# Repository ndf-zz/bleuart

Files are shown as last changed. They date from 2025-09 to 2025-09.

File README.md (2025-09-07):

# bleuart

ESP32 BLE to RS232 bridge

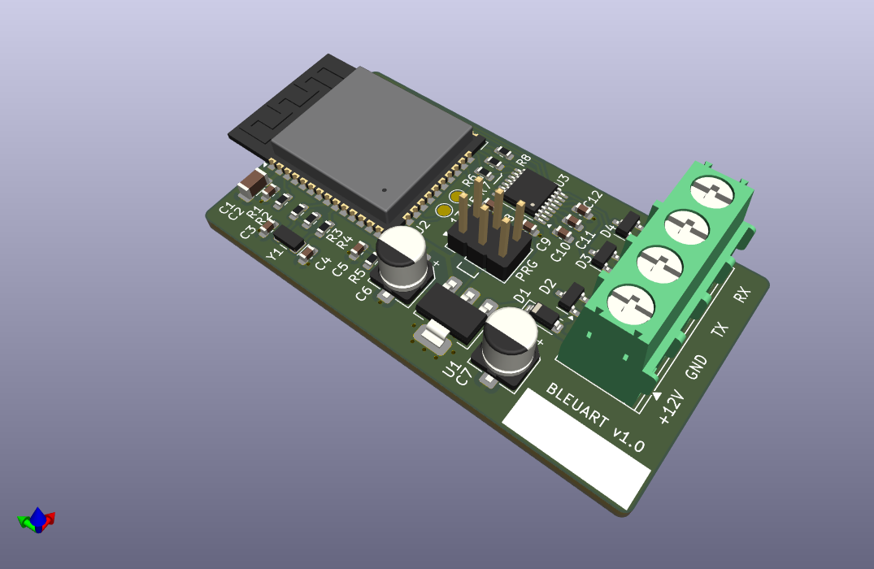
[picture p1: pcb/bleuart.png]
PCB


	BLE  <->  UART  <-- RX (RS232)
	                --> TX (RS232)

Using an ESP32-WROOM-32E module, BLEUART provides
a low-tech BLE to RS232 UART bridge. Data is transferred
via write and notify under a single custom GATT service
with ID 11e6b0a4-99c7-4647-956b-8a57cb5907d9.

Advertises device "location" (CNAME) via
manufacturer data. Initial bonding PIN is 0.

## Characteristics

UUID | Function | Type | Actions
--- | --- | --- | ---
0000b0a4-99c7-4647-956b-8a57cb5907d9 | Pin | uint32 (0-999999) | write
0001b0a4-99c7-4647-956b-8a57cb5907d9 | UART RX | bytes | notify
0010b0a4-99c7-4647-956b-8a57cb5907d9 | UART TX | bytes | write
0100b0a4-99c7-4647-956b-8a57cb5907d9 | CNAME "Location" | bytes | read/write
1000b0a4-99c7-4647-956b-8a57cb5907d9 | DNAME "Device Name" | bytes | write
f074b0a4-99c7-4647-956b-8a57cb5907d9 | FOTA | bytes | write
0x2a26 | Firmware Version | bytes | read

## Known Issues/Limitations

   - Secure boot V1 is used only as a fancy CRC for OTA updates.
     Todo: Move to V2.
   - Re-flashable bootloader needs to be booted once and then re-flashed
     to correct the re-flashable stage 2 digest. Todo: Move to V2 and or
     one-time flash.
   - LE security is circumvented through use of fixed pairing pin. Todo: OOB.
   - Private addrs do not yet work as expected. Todo: Investigate 
     implementation of RPA 0x2ac9.
   - RS232 line driver/receiver is always on, even when device cannot
     receive data due to light sleep. Todo: Use GPIO
     to switch power to line driver.
   - Test pads GPIO13/15 are inaccessible and floating. Todo:
     Add pull-ups and relocate pads with nearby ground pad for
     factory reset option.
   - Reflashable plain text bootloader assumed. Todo: Investigate
     encrypted flash, encrypted OTA transport.
   - App rollback not supported. Todo: Debug OTA partition
     errors in bootloader and check ota rollback tools.

## FOTA

Write SSID and PSK to GATT characteristic 0xf074 separated
by a null character. Eg:

	b'SSID\0wpapskstr'

Device will connect to nominated ssid, fetch firmware 
then reboot. Base URL for update is set in menuconfig
options. In case of error or timeout, device will reboot to
previous firmware.

Update file requested:

	11e6b0a4-99c7-4647-956b-8a57cb5907d9.bin

## Build & Flash

   - Install ESP-IDF & run export
   - Set target
   - Create secure boot signing key if required
   - Run burnin.sh, reboot board and then run reburn.sh

	$ . ../esp-idf/export.sh
	$ idf.py set-target esp32
	$ idf.py secure-generate-signing-key secure_boot_signing_key.pem
	$ ./burnin.sh
	$ ./reburn.sh

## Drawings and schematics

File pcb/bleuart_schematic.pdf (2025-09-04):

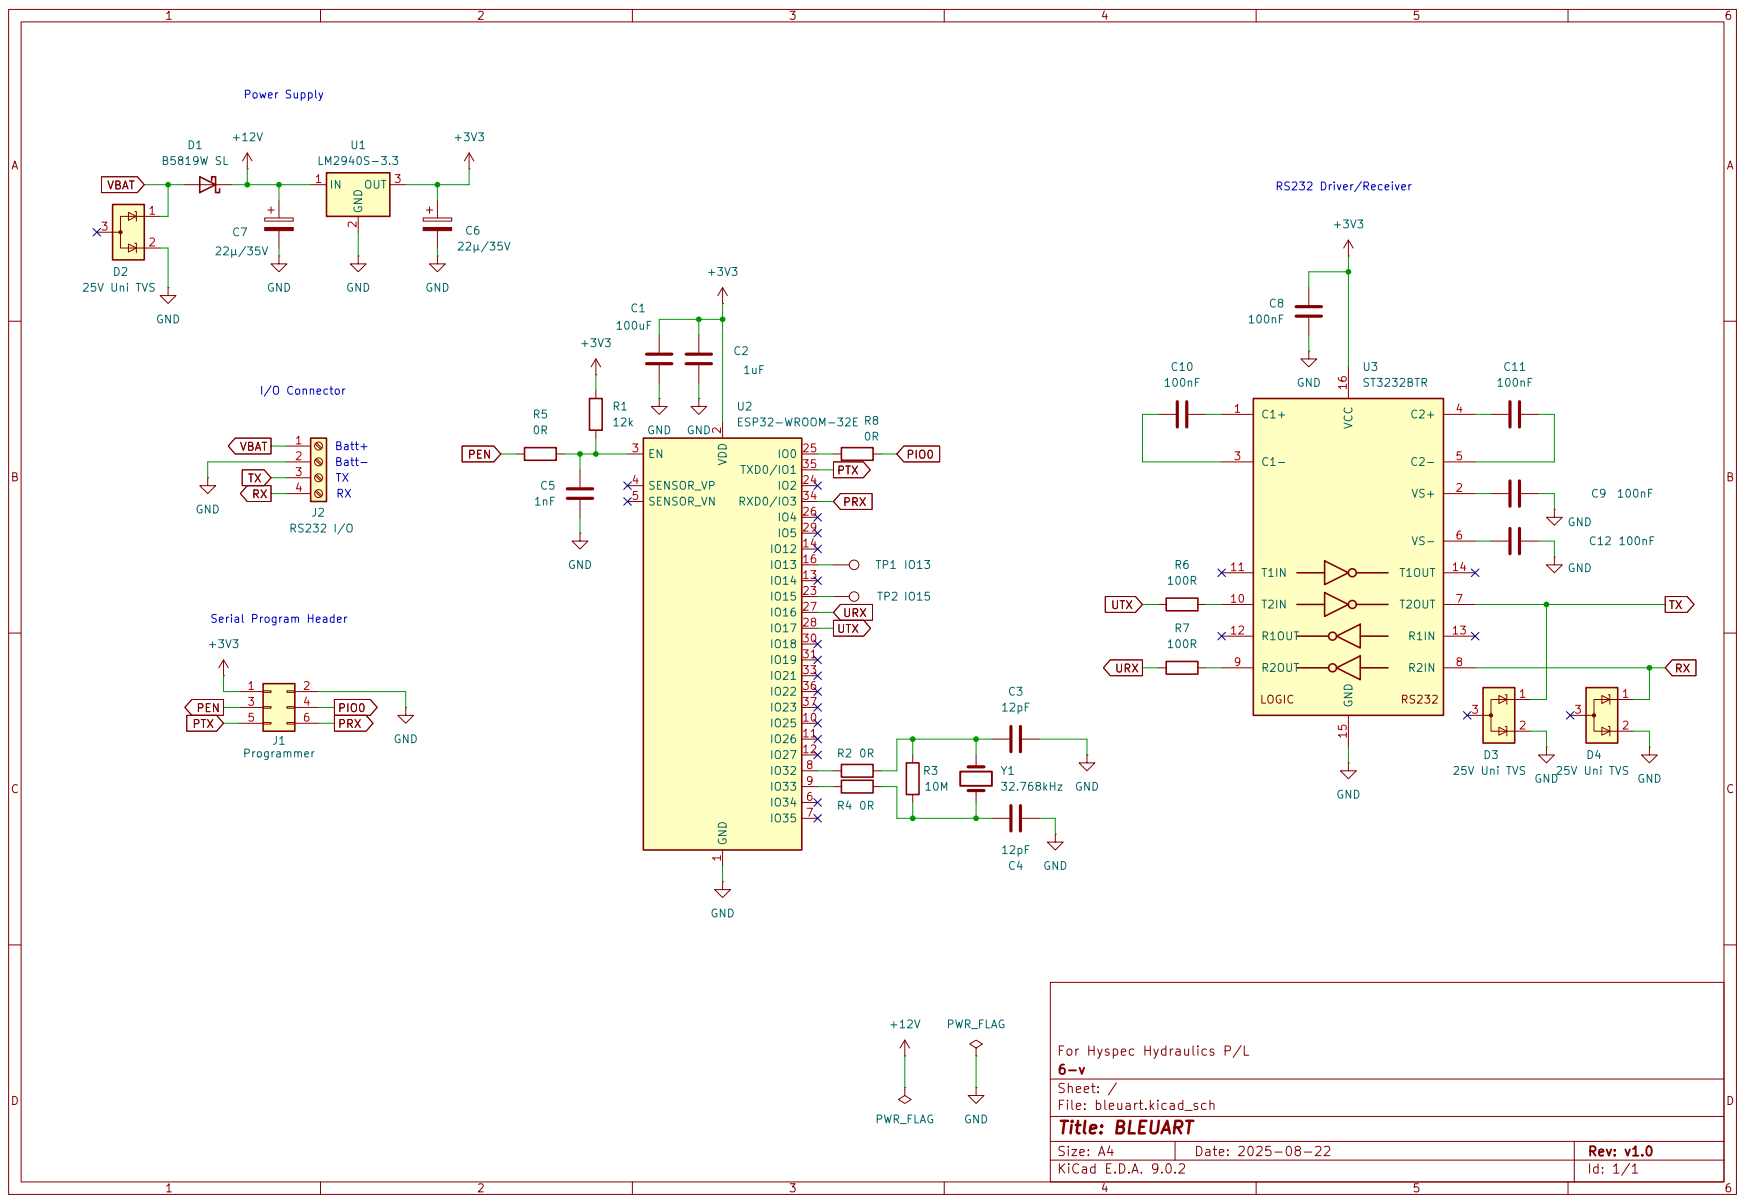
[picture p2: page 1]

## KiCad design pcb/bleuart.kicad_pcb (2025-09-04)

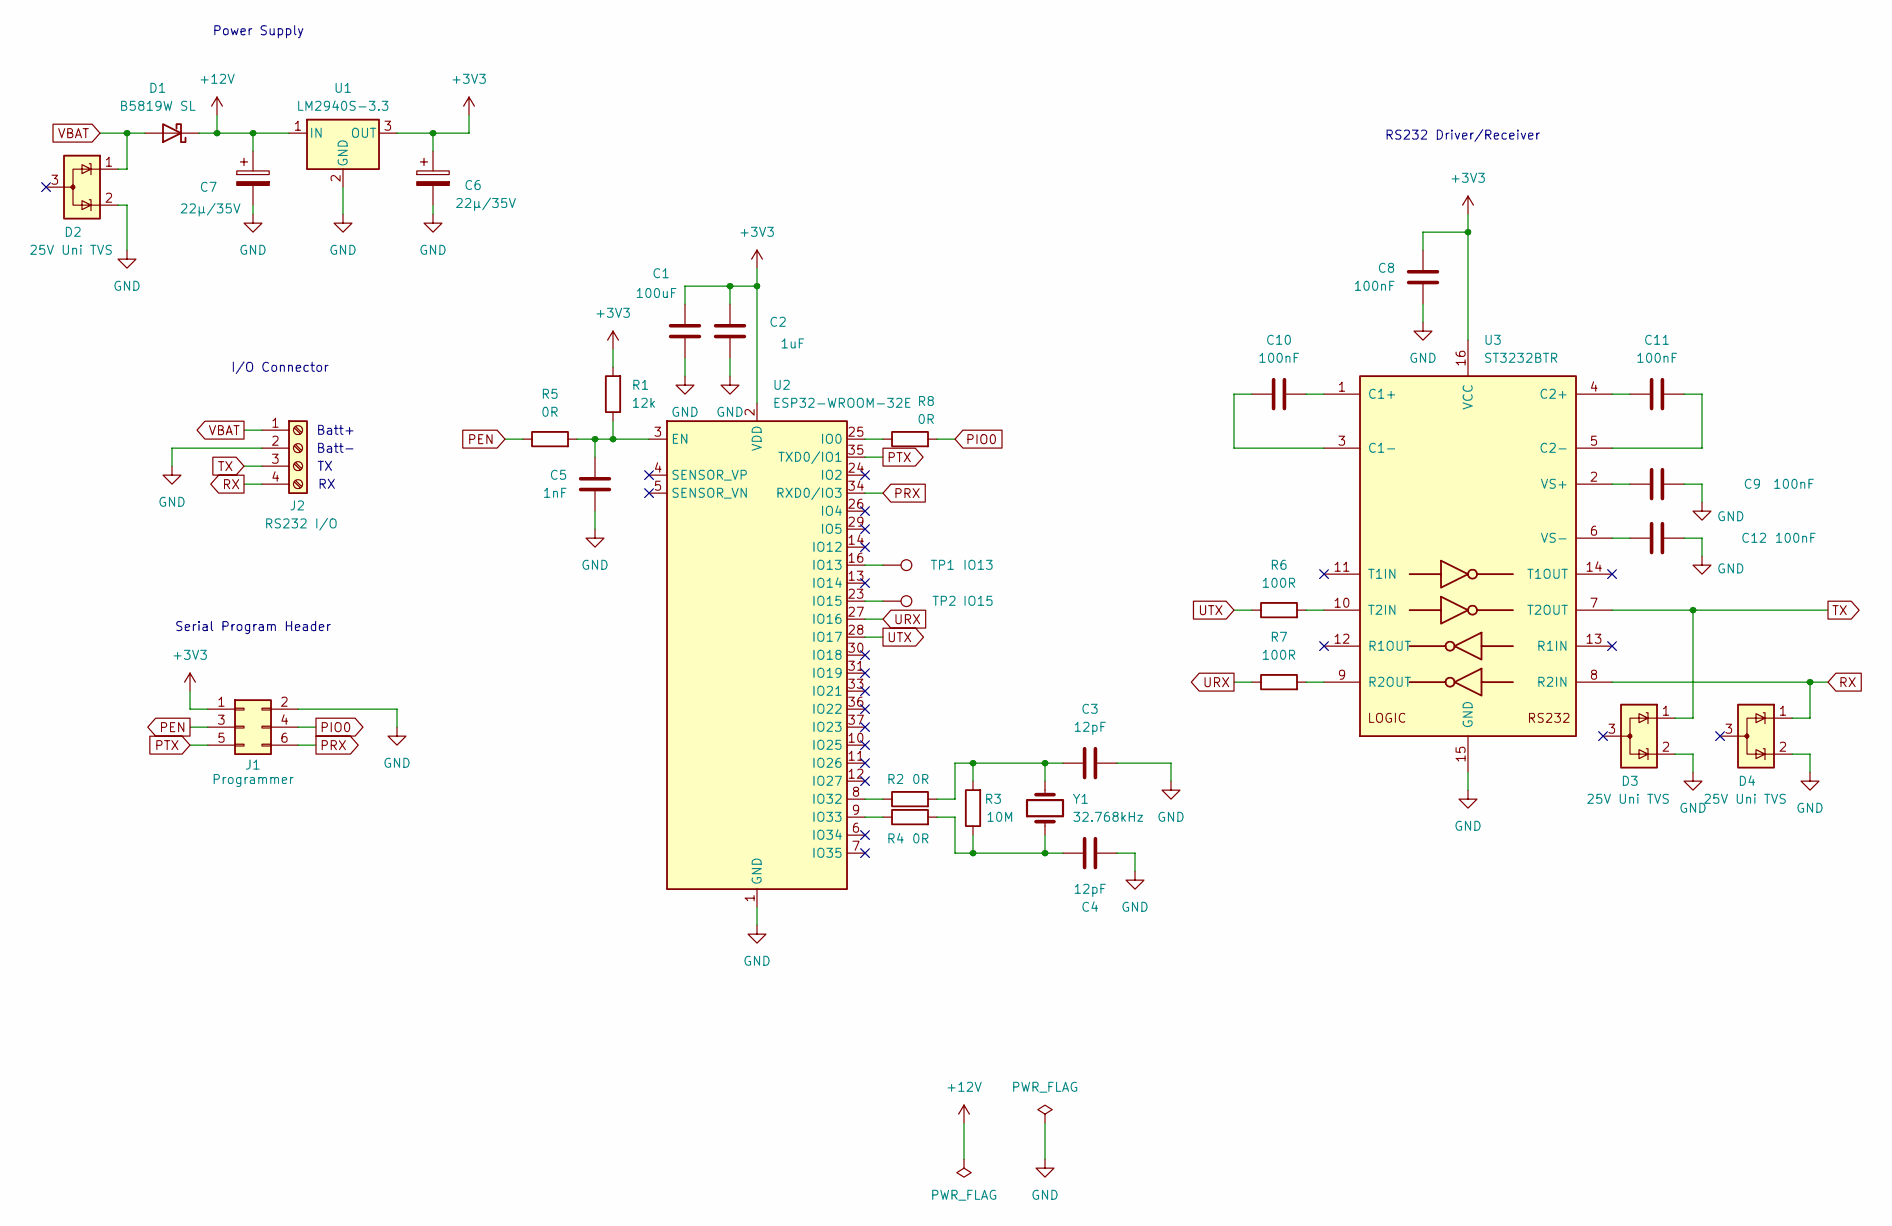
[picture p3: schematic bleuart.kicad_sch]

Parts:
C1: 100uF; C_1206_3216Metric; LCSC C15008
C2: 1uF; C_0603_1608Metric; LCSC C15849
C3, C4: 12pF; C_0603_1608Metric; LCSC C1642
C5: 1nF; C_0603_1608Metric; LCSC C1588
C6, C7: 22µ/35V; CP_Elec_5x5.8; LCSC C494835
C8, C9, C10, C11, C12: 100nF; C_0603_1608Metric; LCSC C14663
D1: B5819W SL; D_SOD-123; LCSC C8598
D2, D3, D4: 25V Uni TVS; SOT-23; LCSC C95343
J1: Programmer; PinHeader_2x03_P2.54mm_Vertical
J2: RS232 I/O; TerminalBlock_Phoenix_PT-1,5-4-5.0-H_1x04_P5.00mm_Horizontal
R1: 12k; R_0603_1608Metric; LCSC C22790
R2, R4, R5, R8: 0R; R_0603_1608Metric; LCSC C95177
R3: 10M; R_0603_1608Metric; LCSC C7250
R6, R7: 100R; R_0603_1608Metric; LCSC C22775
TP1: IO13; TestPoint_Pad_D1.5mm
TP2: IO15; TestPoint_Pad_D1.5mm
U1: LM2940S-3.3; SOT-223-3_TabPin2; LCSC C596335
U2: ESP32-WROOM-32E; LCSC C3013935
U3: ST3232BTR; TSSOP-16_4.4x5mm_P0.65mm; LCSC C118284
Y1: 32.768kHz; Crystal_SMD_MicroCrystal_CC7V-T1A-2Pin_3.2x1.5mm; LCSC C32346

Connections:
+3V3: C1.1, C2.1, C6.1, C8.1, J1.1, R1.2, U1.3 (OUT), U2.2 (VDD), U3.16 (VCC)
+12V: C7.1, D1.1 (K), U1.1 (IN)
GND: C1.2, C2.2, C3.2, C4.2, C5.2, C6.2, C7.2, C8.2, C9.2, C12.2, D2.2 (K), D3.2 (K), D4.2 (K), J1.2, J2.2, U1.2 (GND), U2.1 (GND), U2.15 (GND), U2.38 (GND), U2.39 (GND), U3.15 (GND)
unnamed: C3.1, R2.2, R3.2, Y1.2
unnamed: C4.1, R3.1, R4.2, Y1.1
unnamed: C5.1, R1.1, R5.2, U2.3 (EN)
unnamed: R8.1, U2.25 (IO0)
unnamed: TP1.1, U2.16 (IO13)
unnamed: TP2.1, U2.23 (IO15)
unnamed: R2.1, U2.8 (IO32)
unnamed: R4.1, U2.9 (IO33)
unnamed: C10.2, U3.1 (C1+)
unnamed: C10.1, U3.3 (C1-)
unnamed: C11.1, U3.4 (C2+)
unnamed: C11.2, U3.5 (C2-)
unnamed: R7.2, U3.9 (R2OUT)
unnamed: R6.2, U3.10 (T2IN)
unnamed: C9.1, U3.2 (VS+)
unnamed: C12.1, U3.6 (VS-)
PEN: J1.3, R5.1
PIO0: J1.4, R8.2
PRX: J1.6, U2.34 (RXD0/IO3)
PTX: J1.5, U2.35 (TXD0/IO1)
RX: D4.1 (K), J2.4, U3.8 (R2IN)
TX: D3.1 (K), J2.3, U3.7 (T2OUT)
URX: R7.1, U2.27 (IO16)
UTX: R6.1, U2.28 (IO17)
VBAT: D1.2 (A), D2.1 (K), J2.1

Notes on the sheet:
Batt+
RS232 Driver/Receiver
Power Supply
Batt-
I/O Connector
Serial Program Header

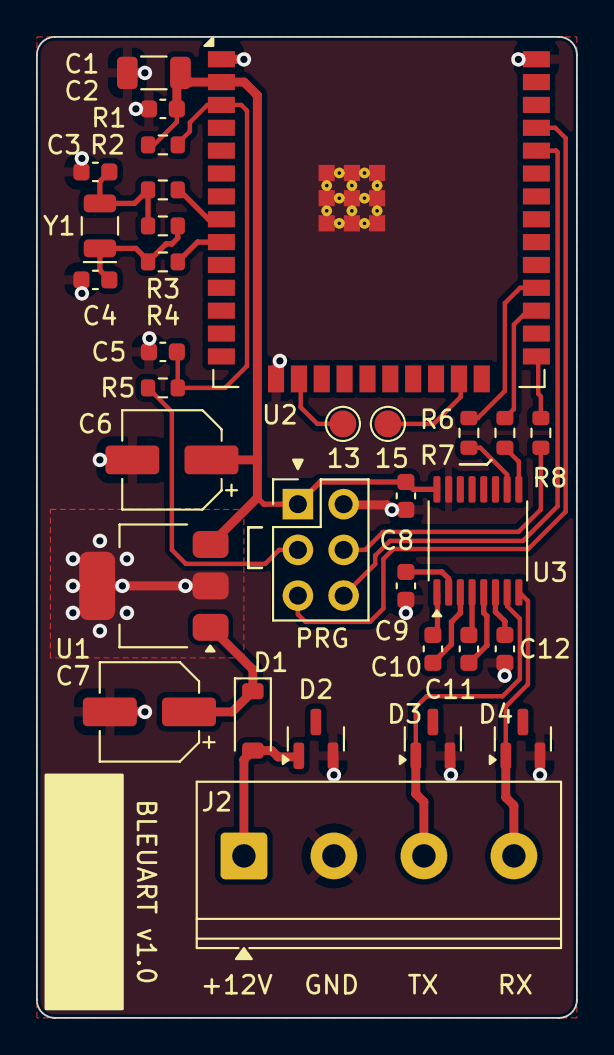
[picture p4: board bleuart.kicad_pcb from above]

Board: 2 copper layers, 30.0 x 54.5 mm, 32 parts (0 on the bottom side), 28 nets.

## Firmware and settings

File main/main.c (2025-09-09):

// SPDX-License-Identifier: MIT

/*
 * BLEUART - BLE to RS232 converter w/ wifi FOTA
 *
 * Based on ESP-IDF examples: uart_echo, https_request, bleprf & power_save
 * 
 * IDF Example code Copyright (C) 2015-2023 Espressif Systems (Apache 2.0)
 * https://docs.espressif.com/projects/esp-idf/en/stable/esp32/COPYRIGHT.html
 *
 * September 2025 ndf-zz@6-v.org
 */

#include "nvs_flash.h"
#include "esp_pm.h"
#include "esp_bt.h"
#include "esp_https_ota.h"
#include "esp_crt_bundle.h"
#include "esp_wifi.h"
#include "driver/uart.h"
#include "host/ble_hs.h"
#include "nimble/nimble_port.h"
#include "host/util/util.h"
#include "services/gap/ble_svc_gap.h"
#include "services/gatt/ble_svc_gatt.h"

// prototypes
void ble_store_config_init(void);  // not in esp hdr
static int gatt_access(uint16_t conn_handle, uint16_t attr_handle,
		     struct ble_gatt_access_ctxt *ctxt, void *arg);
static void wifi_sta_do_disconnect(void);

// build constants
#define BLEUART_DLEN 30  // limit dname string length
#define BLEUART_CLEN 6  // limit cname string length
#define BLEUART_FLEN 98  // limit FOTA trigger length (32+64+sep)
#define BLEUART_ULEN (sizeof(CONFIG_BLEUART_FOTA_URL)+42)  // update URL len
#define BLEUART_PORT 2  // ESP32
#define BLEUART_TXD 17  // ESP32 UART 2 TX GPIO
#define BLEUART_RXD 16  // ESP32 UART 2 RX GPIO
//#define BLEUART_ADVMS 10000  // adv duration
#define BLEUART_ADVMS (BLE_HS_FOREVER)
#define BLEUART_IDLEMS 30000  // main loop idle time
#define BLEUART_RXQLEN 4  // RX event queue len @ 19200 only a few slots reqd
#define BLEUART_BLEN UART_HW_FIFO_LEN(BLEUART_PORT)  // UART RX buffer len
#define BLEUART_CKEY "cname"  // NVS key for CNAME
#define BLEUART_DKEY "dname"  // NVS key for DNAME
#define BLEUART_PKEY "pin"  // NVS key for pairing pin
#define BLEUART_WIFITRY 8  // WIFI connect attempts
#define BLEUART_WIFIMS 5000  // WIFI connect timeout
#define BLEUART_REFLAG (BLE_GATT_CHR_F_READ_ENC | BLE_GATT_CHR_F_READ_AUTHEN)
#define BLEUART_RFLAG (BLE_GATT_CHR_F_READ | BLEUART_REFLAG)
#define BLEUART_WEFLAG (BLE_GATT_CHR_F_READ_ENC | BLE_GATT_CHR_F_READ_AUTHEN)
#define BLEUART_WFLAG (BLE_GATT_CHR_F_WRITE | BLEUART_WEFLAG)
#define BLEUART_KEYFLAG (BLE_SM_PAIR_KEY_DIST_ENC | BLE_SM_PAIR_KEY_DIST_ID)
#define BLEUART_NEFLAG (BLE_GATT_CHR_F_NOTIFY_INDICATE_ENC)
#define BLEUART_NFLAG (BLE_GATT_CHR_F_NOTIFY | BLEUART_NEFLAG)
#define BLEUART_ITVLMIN 30  // min conn interval ~37ms (set after conn est)
#define BLEUART_ITVLMAX 40  // max conn interval ~50ms
#define BLEUART_LATENCY 16  // allow max 16 skipped conn intervals
#define BLEUART_STIMEOUT 200  // conn supervisor timeout ~2s

// task notifcation flags
#define EVT_RESET 0  // stack reset
#define EVT_ADV_INIT (0x1<<0)  // adv init process complete
#define EVT_ADV_START (0x1<<1)  // adv started
#define EVT_CONN (0x1<<2)  // connection established
#define EVT_ADV_END (0x1<<3)  // adv ended
#define EVT_FOTA (0x1<<4)  // request FOTA

// globals
static const char *TAG = "BU";  // log and netif ID
static esp_pm_lock_handle_t sleep_lock;  // light sleep inhibit lock
static QueueHandle_t uart_evq;  // RX event queue
static uint8_t own_addr_type;  // adv_init
static uint8_t addr_val[6];  // adv_init
static TaskHandle_t main_task;  // main
static TaskHandle_t rx_task;  // uart receive task
static esp_netif_t *sta_netif = NULL;  // ota netif
static SemaphoreHandle_t sem_ipv4 = NULL;  // IPv4 assigned
static SemaphoreHandle_t sem_ipv6 = NULL;  // IPv6 assigned
static int wifitry = 0;  // wifi sta connect attempts
static const char *ipv6_addr_types_to_str[6] = {
	"?", "G", "LL", "S", "U", "46"
};

// BLEUART service UUID
static const ble_uuid128_t svc_uuid = BLE_UUID128_INIT(
	0xd9, 0x07, 0x59, 0xcb, 0x57, 0x8a, 0x6b, 0x95,
	0x47, 0x46, 0xc7, 0x99, 0xa4, 0xb0, 0xe6, 0x11
);

// pin 0x0000...
static const ble_uuid128_t pin_uuid = BLE_UUID128_INIT(
	0xd9, 0x07, 0x59, 0xcb, 0x57, 0x8a, 0x6b, 0x95,
	0x47, 0x46, 0xc7, 0x99, 0xa4, 0xb0, 0x00, 0x00
);
static uint16_t pin_handle;
static uint32_t pin = 0;  // ble access key

// UART "RX" 0x0001...
static const ble_uuid128_t rx_uuid = BLE_UUID128_INIT(
	0xd9, 0x07, 0x59, 0xcb, 0x57, 0x8a, 0x6b, 0x95,
	0x47, 0x46, 0xc7, 0x99, 0xa4, 0xb0, 0x01, 0x00
);
static uint8_t rx[BLEUART_BLEN];
static uint16_t rx_handle;
static uint16_t rx_conn_handle;
static bool rx_conn = false;
static bool rx_ind = false;


// UART "TX" 0x0010...
static const ble_uuid128_t tx_uuid = BLE_UUID128_INIT(
	0xd9, 0x07, 0x59, 0xcb, 0x57, 0x8a, 0x6b, 0x95,
	0x47, 0x46, 0xc7, 0x99, 0xa4, 0xb0, 0x10, 0x00
);
static uint16_t tx_handle;

// Unit identifier "CNAME" 0x0100...
static const ble_uuid128_t cname_uuid = BLE_UUID128_INIT(
	0xd9, 0x07, 0x59, 0xcb, 0x57, 0x8a, 0x6b, 0x95,
	0x47, 0x46, 0xc7, 0x99, 0xa4, 0xb0, 0x00, 0x01
);
static uint16_t cname_handle;
static char cname[BLEUART_CLEN+2];
static uint8_t manuf[BLEUART_CLEN+2];

// Device identifier "DNAME" 0x1000...
static const ble_uuid128_t dname_uuid = BLE_UUID128_INIT(
	0xd9, 0x07, 0x59, 0xcb, 0x57, 0x8a, 0x6b, 0x95,
	0x47, 0x46, 0xc7, 0x99, 0xa4, 0xb0, 0x00, 0x10
);
static uint16_t dname_handle;
static char dname[BLEUART_DLEN+2];

// Firmware revision characateristic 0x2a26
static const ble_uuid16_t fwrev_uuid = BLE_UUID16_INIT(0x2a26);
const esp_app_desc_t *app_desc;
static uint16_t fwrev_handle;

// Firmware update trigger 0xf07a...
static const ble_uuid128_t fota_uuid = BLE_UUID128_INIT(
	0xd9, 0x07, 0x59, 0xcb, 0x57, 0x8a, 0x6b, 0x95,
	0x47, 0x46, 0xc7, 0x99, 0xa4, 0xb0, 0x7a, 0xf0
);
static uint16_t fota_handle;
static char fota[BLEUART_FLEN+2];

// GATT service table
static const struct ble_gatt_svc_def gatt_svcs[] = {
	{.type = BLE_GATT_SVC_TYPE_PRIMARY,
	 .uuid = &svc_uuid.u,
	 .characteristics = (struct ble_gatt_chr_def[]) {
		{.uuid = &pin_uuid.u,
		 .access_cb = gatt_access,
		 .flags = BLEUART_WFLAG,
		 .val_handle = &pin_handle
		},
		{.uuid = &rx_uuid.u,
		 .access_cb = gatt_access,
		 .flags = BLEUART_NFLAG,
		 .val_handle = &rx_handle
		},
		{.uuid = &tx_uuid.u,
		 .access_cb = gatt_access,
		 .flags = BLEUART_WFLAG,
		 .val_handle = &tx_handle
		},
		{.uuid = &cname_uuid.u,
		 .access_cb = gatt_access,
		 .flags = BLEUART_RFLAG | BLEUART_WFLAG,
		 .val_handle = &cname_handle
		},
		{.uuid = &dname_uuid.u,
		 .access_cb = gatt_access,
		 .flags = BLEUART_WFLAG,
		 .val_handle = &dname_handle
		},
		{.uuid = &fwrev_uuid.u,
		 .access_cb = gatt_access,
		 .flags = BLEUART_RFLAG,
		 .val_handle = &fwrev_handle
		},
		{.uuid = &fota_uuid.u,
		 .access_cb = gatt_access,
		 .flags = BLEUART_WFLAG,
		 .val_handle = &fota_handle
		},
		{ 0 },
	 },
	},
	{ 0 },
};

// Save whole dname or cname buffer to NVS
static void save_name(const char *key, char *val, size_t len)
{
	nvs_handle_t nvsh;
	esp_err_t rc = nvs_open(TAG, NVS_READWRITE, &nvsh);
	ESP_LOGI(TAG, "sn: open %d", rc);
	if (rc == ESP_OK) {
		rc = nvs_set_blob(nvsh, key, val, len);
		nvs_commit(nvsh);
		nvs_close(nvsh);
		ESP_LOGI(TAG, "sn: %s[%d] %d", key, len, rc);
	}
}

static void save_pin(void)
{
	nvs_handle_t nvsh;
	if (nvs_open(TAG, NVS_READWRITE, &nvsh) == ESP_OK) {
		esp_err_t rc = nvs_set_u32(nvsh, BLEUART_PKEY, pin);
		nvs_commit(nvsh);
		nvs_close(nvsh);
		ESP_LOGI(TAG, "sp: '%lu' %d", pin, rc);
	}
	
}

static int gatt_access(uint16_t conn_handle, uint16_t attr_handle,
			  struct ble_gatt_access_ctxt *ctxt, void *arg)
{
	int rc;
	size_t len;
	ESP_LOGI(TAG,"ga: %d,%d", attr_handle, ctxt->op);
	switch (ctxt->op) {
	case BLE_GATT_ACCESS_OP_READ_CHR:
		if (attr_handle == cname_handle) {
			rc = os_mbuf_append(ctxt->om, &cname[0], BLEUART_CLEN);
			return rc == 0 ? 0 : BLE_ATT_ERR_INSUFFICIENT_RES;
		} else if (attr_handle == fwrev_handle) {
			rc = os_mbuf_append(ctxt->om, &(app_desc->version)[0],
						strlen(app_desc->version));
			return rc == 0 ? 0 : BLE_ATT_ERR_INSUFFICIENT_RES;
		}
		break;
	case BLE_GATT_ACCESS_OP_WRITE_CHR:
		len = ctxt->om->om_len;
		if (attr_handle == tx_handle) {
			ESP_LOGI(TAG, "tx: B>U %d", ctxt->om->om_len);
			uart_write_bytes(BLEUART_PORT,
					 (const char *)ctxt->om->om_data,
					 ctxt->om->om_len);
			return 0;
		} else if (attr_handle == cname_handle) {
			if (len > BLEUART_CLEN) {
				len = BLEUART_CLEN;
			}
			memset(&cname[0], 0x00, BLEUART_CLEN);
			memcpy(&cname[0], ctxt->om->om_data, len);
			save_name(BLEUART_CKEY, &cname[0], BLEUART_CLEN);
			return 0;
		} else if (attr_handle == dname_handle) {
			if (len > BLEUART_DLEN) {
				len = BLEUART_DLEN;
			}
			memset(&dname[0], 0x00, BLEUART_DLEN);
			memcpy(&dname[0], ctxt->om->om_data, len);
			save_name(BLEUART_DKEY, &dname[0], BLEUART_DLEN);
			ble_svc_gap_device_name_set(dname);
			return 0;
		} else if (attr_handle == pin_handle) {
			if (len == 4) {
				pin = ctxt->om->om_data[0]&0xff;
				pin |= (ctxt->om->om_data[1]<<8)&0xff00;
				pin |= (ctxt->om->om_data[2]<<16)&0xff0000;
				pin |= (ctxt->om->om_data[3]<<24)&0xff000000;
				if (pin > 999999) {
					pin = 999999;
				}
				save_pin();
			} else {
				ESP_LOGE(TAG, "p: bad");
				return BLE_ATT_ERR_INVALID_ATTR_VALUE_LEN;
			}
			return 0;
		} else if (attr_handle == fota_handle) {
			if (len > BLEUART_FLEN) {
				len = BLEUART_FLEN;
			}
			memset(&fota[0], 0x00, BLEUART_FLEN);
			memcpy(&fota[0], ctxt->om->om_data, len);
			// notify main proc
			xTaskNotify(main_task, EVT_FOTA,
					eSetValueWithOverwrite);
			return 0;
		}
		break;
	default:
		break;
	}
	ESP_LOGI(TAG, "ga: unlikely");
	return BLE_ATT_ERR_UNLIKELY;
}

void subscribe_cb(struct ble_gap_event *event)
{
	if (event->subscribe.attr_handle == rx_handle) {
		rx_conn_handle = event->subscribe.conn_handle;
		rx_conn = true;
		rx_ind = event->subscribe.cur_notify;
		if (rx_ind) {
			esp_pm_lock_acquire(sleep_lock);
			ESP_LOGI(TAG, "ls: a");
		} else {
			esp_pm_lock_release(sleep_lock);
			ESP_LOGI(TAG, "ls: r");
		}
	}
}

static void format_addr(char *addr_str, uint8_t addr[])
{
	sprintf(addr_str, "%02X:%02X:%02X:%02X:%02X:%02X", addr[5], addr[4],
		addr[3], addr[2], addr[1], addr[0]);
}

static void log_conn(struct ble_gap_conn_desc *desc)
{
	char addr_str[18] = {0};
	format_addr(addr_str, desc->peer_id_addr.val);
	ESP_LOGI(TAG, "cn: %d %s %d,%d,%d",
		desc->conn_handle, addr_str, desc->sec_state.encrypted,
		desc->sec_state.authenticated, desc->sec_state.bonded);
}

static void update_manuf(void)
{
	int mid = CONFIG_BLEUART_MID;
	manuf[0] = (uint8_t)(mid & 0xff);
	manuf[1] = (uint8_t)((mid >> 8) & 0xff);
	memcpy((char *)&manuf[2], &cname[0], BLEUART_CLEN);
}

static int gap_event(struct ble_gap_event *event, void *arg)
{
	int rc = 0;
	struct ble_gap_conn_desc desc;

	switch (event->type) {
	case BLE_GAP_EVENT_CONNECT:
		ESP_LOGW(TAG, "ce: %d", event->connect.status);
		ble_gap_conn_find(event->connect.conn_handle, &desc);
		log_conn(&desc);
		// update latency and supervision timeout
		struct ble_gap_upd_params params = {
			.itvl_min = BLEUART_ITVLMIN ,
			.itvl_max = BLEUART_ITVLMAX,
			.latency = BLEUART_LATENCY,
			.supervision_timeout = BLEUART_STIMEOUT,
		};
		rc = ble_gap_update_params(event->connect.conn_handle, &params);
		ESP_LOGI(TAG, "ce: up = %d", rc);
		xTaskNotify(main_task, EVT_CONN, eSetBits);
		break;
	case BLE_GAP_EVENT_DISCONNECT:
		ESP_LOGW(TAG, "dc: %d", event->disconnect.reason);
		rx_conn = false;
		rx_conn_handle = 0;
		esp_pm_lock_release(sleep_lock);
		ESP_LOGI(TAG, "ls: re");
		xTaskNotify(main_task, EVT_ADV_INIT, eSetValueWithOverwrite);
		break;
	case BLE_GAP_EVENT_CONN_UPDATE:
		ESP_LOGI(TAG, "cu: %d", event->conn_update.status);
		ble_gap_conn_find(event->conn_update.conn_handle, &desc);
		log_conn(&desc);
		break;
	case BLE_GAP_EVENT_ADV_COMPLETE:
		ESP_LOGI(TAG, "ac: %d", event->adv_complete.reason);
		xTaskNotify(main_task, EVT_ADV_END, eSetBits);
		break;
	case BLE_GAP_EVENT_SUBSCRIBE:
		ESP_LOGI(TAG, "gs: %d n: %d>%d i: %d>%d",
			 event->subscribe.attr_handle,
			 event->subscribe.prev_notify,
			 event->subscribe.cur_notify,
			 event->subscribe.prev_indicate,
			 event->subscribe.cur_indicate);
		subscribe_cb(event);
		break;
	case BLE_GAP_EVENT_NOTIFY_TX:
		xTaskNotify(rx_task, event->notify_tx.status,
				eSetValueWithOverwrite);
		break;
	case BLE_GAP_EVENT_ENC_CHANGE:
		ble_gap_conn_find(event->enc_change.conn_handle, &desc);
		log_conn(&desc);
		break;
	case BLE_GAP_EVENT_PASSKEY_ACTION:
		struct ble_sm_io pkey = {0};
		if (event->passkey.params.action == BLE_SM_IOACT_DISP) {
			pkey.action = event->passkey.params.action;
			pkey.passkey = pin;
			ESP_LOGW(TAG, "pk: %lu", pkey.passkey);
		}
		rc = ble_sm_inject_io(event->passkey.conn_handle, &pkey);
		break;
	case BLE_GAP_EVENT_AUTHORIZE:
		ESP_LOGI(TAG, "au: %d %d",
		    event->authorize.conn_handle,
		    event->authorize.attr_handle,
		    event->authorize.is_read);
		event->authorize.out_response = BLE_GAP_AUTHORIZE_ACCEPT;
		break;
	case BLE_GAP_EVENT_REPEAT_PAIRING:
		ESP_LOGI(TAG, "rp: %d", event->repeat_pairing.conn_handle);
		ble_gap_conn_find(event->repeat_pairing.conn_handle, &desc);
		ble_store_util_delete_peer(&desc.peer_id_addr);
		return BLE_GAP_REPEAT_PAIRING_RETRY;
		break;
	case BLE_GAP_EVENT_IDENTITY_RESOLVED:
		ESP_LOGI(TAG, "ir");
		break;
	default:
		ESP_LOGI(TAG, "ge: %d", event->type);
		break;
	}
	return rc;
}

static void start_advertising(void)
{
	struct ble_hs_adv_fields adv_fields = {0};
	struct ble_hs_adv_fields rsp_fields = {0};
	struct ble_gap_adv_params adv_params = {0};

	// fill and set adv fields
	update_manuf();
	adv_fields.flags = BLE_HS_ADV_F_DISC_GEN | BLE_HS_ADV_F_BREDR_UNSUP;
	adv_fields.tx_pwr_lvl = 9;
	adv_fields.tx_pwr_lvl_is_present = 1;
	adv_fields.appearance = CONFIG_BLEUART_APPEARANCE;
	adv_fields.appearance_is_present = 1;
	adv_fields.le_role = 0x00;
	adv_fields.le_role_is_present = 1;
	adv_fields.mfg_data = &manuf[0];
	adv_fields.mfg_data_len = BLEUART_CLEN + 2;
	ble_gap_adv_set_fields(&adv_fields);

	// fill and set rsp
	rsp_fields.device_addr = addr_val;
	rsp_fields.device_addr_type = own_addr_type;
	rsp_fields.device_addr_is_present = 1;
	rsp_fields.adv_itvl = BLE_GAP_ADV_FAST_INTERVAL2_MIN;
	rsp_fields.adv_itvl_is_present = 1;
	//rsp_fields.uuids128 = &svc_uuid;
	//rsp_fields.num_uuids128 = 1;
	//rsp_fields.uuids128_is_complete = 1;
	ble_gap_adv_rsp_set_fields(&rsp_fields);

	adv_params.conn_mode = BLE_GAP_CONN_MODE_UND;
	adv_params.disc_mode = BLE_GAP_DISC_MODE_GEN;
	adv_params.itvl_min = BLE_GAP_ADV_FAST_INTERVAL2_MIN;
	adv_params.itvl_max = BLE_GAP_ADV_FAST_INTERVAL2_MAX;
	ble_gap_adv_start(own_addr_type, NULL, BLEUART_ADVMS, &adv_params,
				gap_event, NULL);
	xTaskNotify(main_task, EVT_ADV_START, eSetBits);
}

static void adv_init(void)
{
	ble_hs_util_ensure_addr(0);
	ble_hs_id_infer_auto(0, &own_addr_type);
	ble_hs_id_copy_addr(own_addr_type, addr_val, NULL);
	char addr_str[18] = {0};
	format_addr(addr_str, addr_val);
	ESP_LOGI(TAG, "oa: %s", addr_str);
	xTaskNotify(main_task, EVT_ADV_INIT, eSetBits);
}

static void on_stack_reset(int reason)
{
	xTaskNotify(main_task, EVT_RESET, eSetValueWithOverwrite);
}

static void ble_host(void *param)
{
	nimble_port_run();  // does not return in this case
}

static void rx_notify(const void *buf, uint16_t len)
{
	struct os_mbuf *mb = ble_hs_mbuf_from_flat(buf, len);
	if (mb != NULL) {
		ble_gatts_notify_custom(rx_conn_handle, rx_handle, mb);
		xTaskNotifyWait(0, ULONG_MAX, NULL, portMAX_DELAY);
		// ignore result of notify for now
	} else {
		ESP_LOGE(TAG, "rx: mem");
	}
}

static void read_uart(void)
{
	size_t avail = 0;

	uart_get_buffered_data_len(BLEUART_PORT, &avail);
	ESP_LOGI(TAG,"av: %d", avail);
	if (avail) {
		// pull as much out of uart as will fit in rx buffer
		if (avail > BLEUART_BLEN) {
			avail = BLEUART_BLEN;
		}
		uint16_t rx_len = uart_read_bytes(BLEUART_PORT, &rx[0],
						avail, portMAX_DELAY);
		ESP_LOGI(TAG, "rx: U>X %d", rx_len);
		if (rx_len && rx_ind && rx_conn) {
			rx_notify(&rx[0], rx_len);
		}
	}
}

static void uart_receive(void)
{
	uart_event_t event;
	if (xQueueReceive(uart_evq, (void *)&event, portMAX_DELAY)) {
		switch (event.type) {
		case UART_DATA:
			read_uart();
			break;
		case UART_FIFO_OVF:
		case UART_BUFFER_FULL:
			ESP_LOGW(TAG, "ua: o/f");
			uart_flush(BLEUART_PORT);
			xQueueReset(uart_evq);
			break;
		default:
			ESP_LOGI(TAG, "ua: evt %d", event.type);
			break;
		}
	}
}

static void uart_rx(void *arg)
{
	do {
		uart_receive();
	} while (1);
}

static bool own_netif(const char *prefix, esp_netif_t *netif)
{
	return strncmp(prefix, esp_netif_get_desc(netif),
			strlen(prefix) - 1) == 0;
}

static void on_wifi_disconnect(void *arg, esp_event_base_t event_base,
			       int32_t event_id, void *event_data)
{
	wifitry++;
	if (wifitry > BLEUART_WIFITRY) {
		ESP_LOGI(TAG, "wf: %d", wifitry);
		if (sem_ipv4) {
			xSemaphoreGive(sem_ipv4);
		}
		if (sem_ipv6) {
			xSemaphoreGive(sem_ipv6);
		}
		wifi_sta_do_disconnect();
		return;
	}
	wifi_event_sta_disconnected_t *disconn = event_data;
	if (disconn->reason == WIFI_REASON_ROAMING) {
		return;
	}
	ESP_LOGI(TAG, "wf: d/c %d", disconn->reason);
	esp_wifi_connect();
}

static void on_sta_got_ipv4(void *arg, esp_event_base_t event_base,
		      int32_t event_id, void *event_data)
{
	wifitry = 0;
	ip_event_got_ip_t *event = (ip_event_got_ip_t *)event_data;
	if (!own_netif(TAG, event->esp_netif)) {
		return;
	}
	ESP_LOGI(TAG, "v4: " IPSTR, IP2STR(&event->ip_info.ip));
	if (sem_ipv4) {
		xSemaphoreGive(sem_ipv4);
	}
}

static void on_sta_got_ipv6(void *arg, esp_event_base_t event_base, 
			int32_t event_id, void *event_data)
{
	ip_event_got_ip6_t *event = (ip_event_got_ip6_t *)event_data;
	if (!own_netif(TAG, event->esp_netif)) {
		return;
	}
	esp_ip6_addr_type_t ipv6_type = esp_netif_ip6_get_addr_type(&event->ip6_info.ip);
	ESP_LOGI(TAG, "v6[%s]: " IPV6STR, ipv6_addr_types_to_str[ipv6_type],
		IPV62STR(event->ip6_info.ip));
	if (ipv6_type == ESP_IP6_ADDR_IS_GLOBAL) {
		if (sem_ipv6) {
			xSemaphoreGive(sem_ipv6);
		}
	}
}

static void on_wifi_connect(void *esp_netif, esp_event_base_t event_base,
			    int32_t event_id, void *event_data)
{
	esp_netif_create_ip6_linklocal(esp_netif);
}

static void wifi_sta_do_disconnect(void)
{
	esp_event_handler_unregister(WIFI_EVENT, WIFI_EVENT_STA_DISCONNECTED,
					&on_wifi_disconnect);
	esp_event_handler_unregister(IP_EVENT, IP_EVENT_STA_GOT_IP,
					 &on_sta_got_ipv4);
	esp_event_handler_unregister(WIFI_EVENT, WIFI_EVENT_STA_CONNECTED,
					 &on_wifi_connect);
	esp_event_handler_unregister(IP_EVENT, IP_EVENT_GOT_IP6,
					 &on_sta_got_ipv6);
	esp_wifi_disconnect();
}

static void wifi_connect(char *ssid, char *psk)
{
	wifi_init_config_t cfg = WIFI_INIT_CONFIG_DEFAULT();
	ESP_ERROR_CHECK(esp_wifi_init(&cfg)); 
	esp_netif_inherent_config_t esp_netif_config = ESP_NETIF_INHERENT_DEFAULT_WIFI_STA();
	esp_netif_config.if_desc = TAG;
	esp_netif_config.route_prio = 128;
	sta_netif = esp_netif_create_wifi(WIFI_IF_STA, &esp_netif_config);
	esp_wifi_set_default_wifi_sta_handlers();
	esp_wifi_set_storage(WIFI_STORAGE_RAM);
	esp_wifi_set_mode(WIFI_MODE_STA);
	esp_wifi_start();
	wifi_config_t wifi_config = {
	.sta = {
		.ssid = { 0 },
		.password =  { 0 },
		.scan_method = WIFI_ALL_CHANNEL_SCAN,
		.sort_method = WIFI_CONNECT_AP_BY_SIGNAL,
		.threshold.rssi = -127,
		.threshold.authmode = WIFI_AUTH_WPA2_PSK,
		},
	};
	strncpy((char *)&wifi_config.sta.ssid[0], ssid, 32);
	strncpy((char *)&wifi_config.sta.password[0], psk, 64);
	sem_ipv4 = xSemaphoreCreateBinary();
	if (sem_ipv4 == NULL) {
		return;
	}
	sem_ipv6 = xSemaphoreCreateBinary();
	if (sem_ipv6 == NULL) {
		vSemaphoreDelete(sem_ipv4);
		return;
	}
	wifitry = 0;
	esp_event_handler_register(WIFI_EVENT, WIFI_EVENT_STA_DISCONNECTED,
					&on_wifi_disconnect, NULL);
	esp_event_handler_register(IP_EVENT, IP_EVENT_STA_GOT_IP,
					&on_sta_got_ipv4, NULL);
	esp_event_handler_register(WIFI_EVENT, WIFI_EVENT_STA_CONNECTED,
					&on_wifi_connect, sta_netif);
	esp_event_handler_register(IP_EVENT, IP_EVENT_GOT_IP6,
					&on_sta_got_ipv6, NULL);
	esp_wifi_set_config(WIFI_IF_STA, &wifi_config);
	esp_err_t ret = esp_wifi_connect();
	if (ret != ESP_OK) {
		ESP_LOGE(TAG, "wc: %x", ret);
		return;
	}
	xSemaphoreTake(sem_ipv4, portMAX_DELAY);
	vSemaphoreDelete(sem_ipv4);
	sem_ipv4 = NULL;
	xSemaphoreTake(sem_ipv6, portMAX_DELAY);
	vSemaphoreDelete(sem_ipv6);
	sem_ipv6 = NULL;
}
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
void app_main(void)
{
	//nvs_flash_erase();
	main_task = xTaskGetCurrentTaskHandle();
	app_desc = esp_app_get_description();
	bu_nvs_init();
	bu_pm_init();
	bu_ble_init();
	bu_init_uart();

	// start BLE and UART tasks - pinned to cpu 1
	xTaskCreatePinnedToCore(ble_host, "ble_host", 4096, NULL, 3, NULL, 1);
	xTaskCreatePinnedToCore(uart_rx, "uart_rx", 2432, NULL, 3, &rx_task, 1);

	// manage BLE advertisement in a loop
	uint32_t ev;
	do {
		if (xTaskNotifyWait(0, 0, &ev,
				BLEUART_IDLEMS / portTICK_PERIOD_MS)) {
			ESP_LOGI(TAG, "mn: 0x%02lx", ev);
			if (ev == EVT_ADV_INIT) {
				start_advertising();
			} else if (ev & EVT_FOTA) {
				xTaskCreatePinnedToCore(start_fota, "fota",
						4096, NULL, 3, NULL, 1);
			}
		} else if (ev & EVT_ADV_END) {
			xTaskNotify(main_task, EVT_ADV_INIT,
						eSetValueWithOverwrite);
		}
	} while (1);
}
